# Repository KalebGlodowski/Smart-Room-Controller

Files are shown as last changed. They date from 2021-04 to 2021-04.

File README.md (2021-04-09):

# Kaleb's Smart Room Controller

## Overview
The purpose of this project is to increase automation within Blink (my cat)'s living environment.

1. Turn on the air freshener and hue lights when the cat is detected entering her litter box
1. Detect the temperature of the cat's room and light up LED's on the board accordingly.
		-flash hue lights when the temperature changes enough to change LED colors
1. 3D model a button knob for the encoder using this link: https://www.sparkfun.com/products/15141
		-click on the features tab in the link
1. Full user input to adjust hue lights
		-Change brightness via potentiometer
		-Change active light via encoder
		-Turn on active light with a single click
		-Change active light color with a long press
1. Keypad that takes in a passcode input
		-locks all user inputs when code is not entered
		-unlocks when correct passcode is entered
		-keypad can be re-locked via the '#' key

1. Display lock/unlock status on OLED

### The controller will have the ability to be manually controlled ontop of the automatic triggers.

## Details

This project uses the following components:

* Phillips hue lights
* Breadboard
* Wires
* Teensy 3.2 microcontroller
* Ultrasonic Sensor (the 2x giant silver circles) | Sends signal, encounters obstacle, then comes back and calculates distance

Can look into more parts: https://www.elegoo.com/products/elegoo-37-in-1-sensor-kit?_pos=1&_sid=ba0552267&_ss=r

## Summary

Automated hue lights, automated air-freshener through a Wemo outlet and fully adjustable hue lights through user input on the board.

You can find me on Hackster here: https://www.hackster.io/kalebglodowski .
And on LinkedIn here: https://www.linkedin.com/in/kalebglodowski/ .

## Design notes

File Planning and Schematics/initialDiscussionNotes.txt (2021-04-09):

Sensor to detect when cat enters litterbox and then send a signal to turn on airfreshener
	Airfreshener = Weemo ON + Wax melter outlet plug
	Sensor = ultrasonic sensor

Sensor to detect when cat goes to eat her food and turn on soft light
	hue lights ON, soft violet
	sensor = ultrasonic sensor

Detect how much water cat has left in her bowl and use the tubing to refill her water bowl /// not enough time/know-how

Pull weather data from online and then light a hue light depending on the temperature outside. Also light neoPixels depending on the rain status. //do not know how, nixed for time

Have the teensy turn on your computer when you press a button //do not know how and does not fit the theme

Allow Hue light to fully controllable manually via the buttons/encoder/potentiometer on the board

Require a password for to access the user manual controls

^ Above are the notable notes/ideas i discussed with my wife Zoe, my friend Austin, my mom, and Cecilia. Not all are included in the project.

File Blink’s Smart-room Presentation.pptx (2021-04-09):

## Blink’s Smart-room controller

created by kaleb glodowski

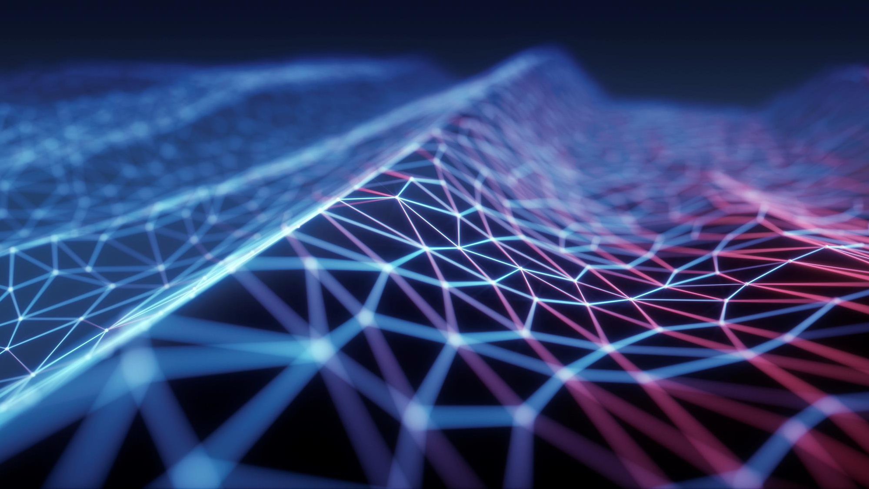
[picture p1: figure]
Digital Connections

## Overview

Planning
Code
Demo

## Planning | Fritzing and components

Components:
Teensy 3.2
Encoder
Potentiometer
Ultrasonic Sensor***
Ethernet port
BME sensor
OLED
NeoPixels & NeoPixel Ring
During the planning phase, I knew I wanted to incorporate most of the components we have learned to use thus far.
***Ultrasonic Sensor is a new component that we have not used yet that can detect and determine how far away an object is.

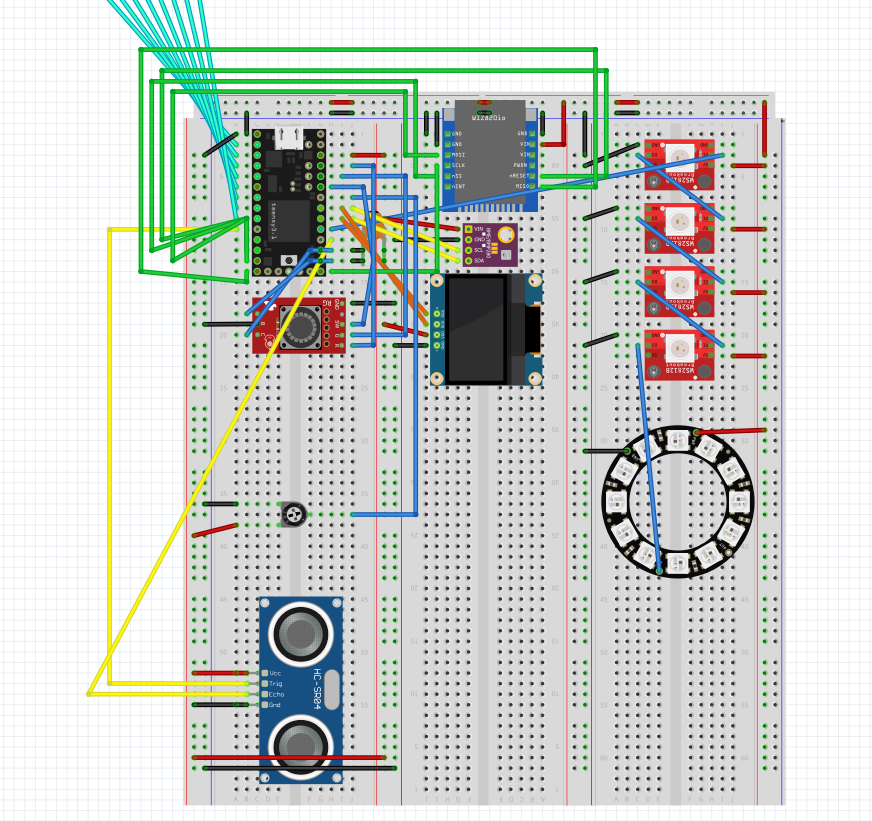
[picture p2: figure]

Note: The cyan wires go-to the keypad off-screen.

## Planning | Main features

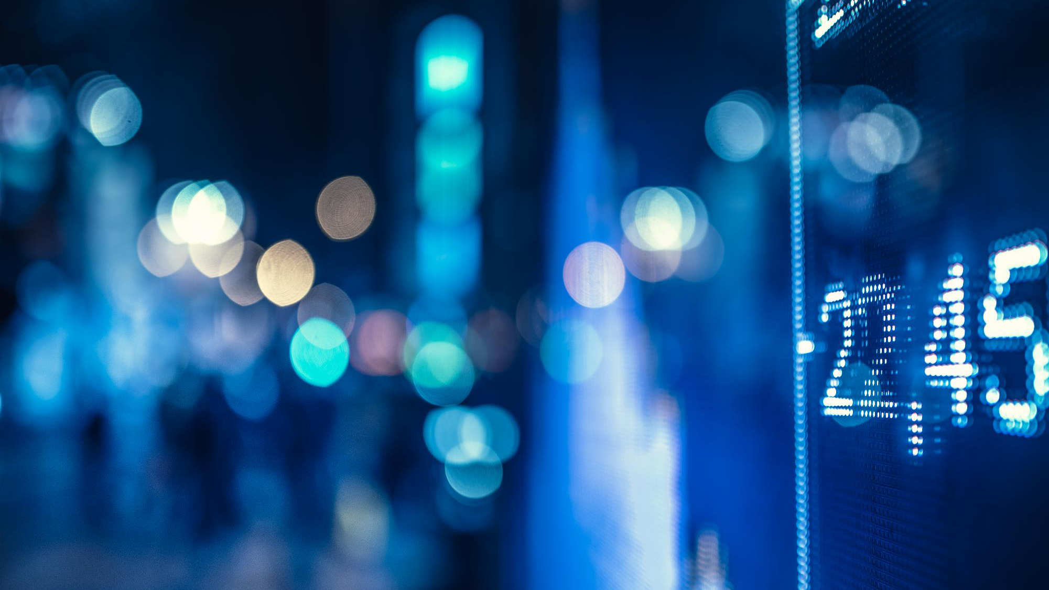
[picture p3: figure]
Digital Numbers

Temperature detection
Auto air-freshener
Full user-input light control

## Code

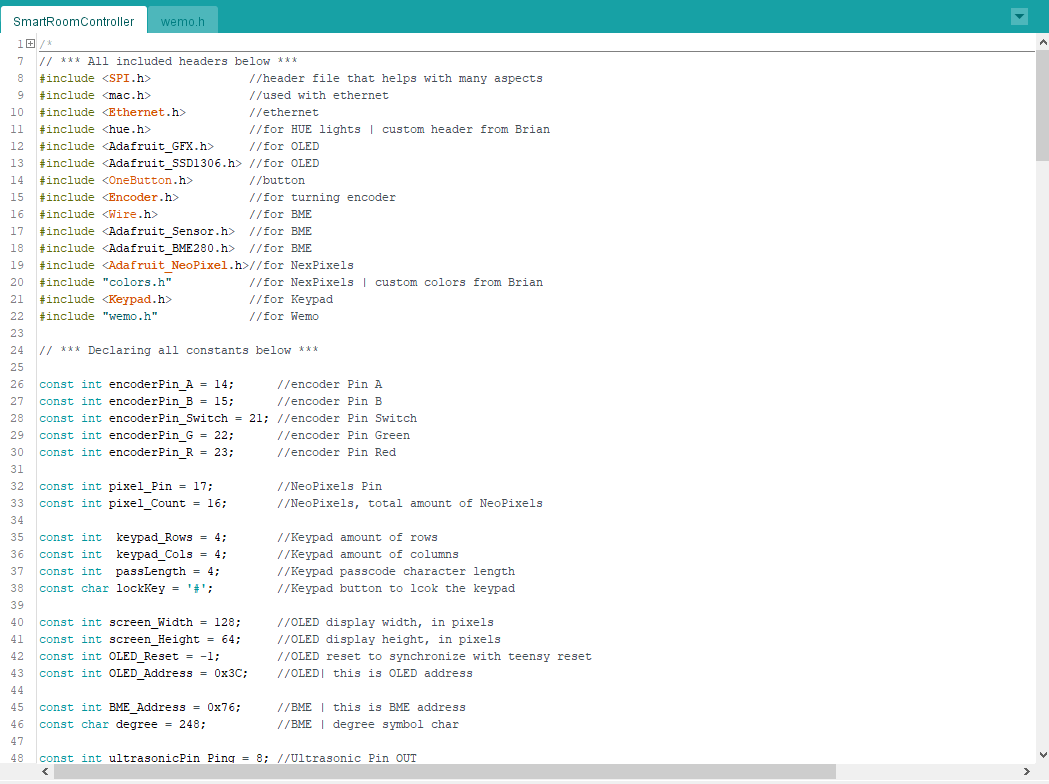
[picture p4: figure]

Main Focus | Organization
Knew that it would be a lot of code. Knowing what is going on in the hundreds of lines of code was essential.
Challenges | Weemo Outlet
>Interference from uSD reader
The ethernet port was checking to see if it was free to accept data but the uSD card was also plugged in and was returning a bunch of non-sense data through the same line (MISO). The code was then breaking when running code from the Weemo header.
To fix this, I had to turn off SPI devices. See code below:

## Demo | Outline

Automation

Manual

- BME
- Ultrasonic Sensor

- Keypad Lock
- Manual Air-Freshener
- Hue Control

## automation | BME & feedback

BME
NeoPixels
Hue Light
Reads the temperature in the room
Lights up red, yellow, or blue depending on the BME reading
Flashes the same color as the NeoPixels when there is a big enough temperature change to change the color of the NeoPixels. After the flash, the Hue lights will then revert back to their previous settings.

## automation | Ultrasonic sensor & Feedback

Ultrasonic Sensor
The ultrasonic sensor is going to detect if there is an object passing between the wall and itself. If there is, then it will automatically turn on the Weemo outlet and Hue lightbulbs.
Wemo
When the ultrasonic sensor detects something passing by, the Wemo outlet connected to air freshener will turn on for a set time. When the timer hits the specified time, the Wemo outlet will turn back off.
Hue Lights
The hue lights are acting as feedback and to light the room when the ultrasonic sensor detects an object passing it. These lights are on the same timer as the Wemo and will turn off automatically when the time is up.

  - As additional feedback, the encoder LED turns green while the Weemo and Hue lights are on, then turns back to red when they are off.

Encoder LED

## manual | keypad lock

Keypad Locked
Enter correct passcode
Keypad Unlocked
Enter the ‘#’ key

All user-input is not accessible while the keypad is locked.

Once the keypad is unlocked, the ‘#’ key can be entered to re-lock all manual inpuet.

OLED displays “LOCKED!”

A 4 digit passcode must be entered to unlock the keypad. When an incorrect digit is entered, you will be prompted to restart entering the code at position one(s=0).
If position 4(s=3) is entered correctly, the keypad will unlock.

All user-input is accessible once the keypad has been unlocked

OLED displays “UNLOCKED! ”

## manual | air freshener

Doubleclick button

The Wemo outlet will turn on/off.

The Hue lightbulbs will turn on/off.

A timer will auto turn off the lights if they are not manually turned off beforehand.

## manual | hue control

Click button

Long press button

Turn potentiometer

Turn encoder

turn on/off light

change color of light

change brightness of the light

change selected light

## Thank You

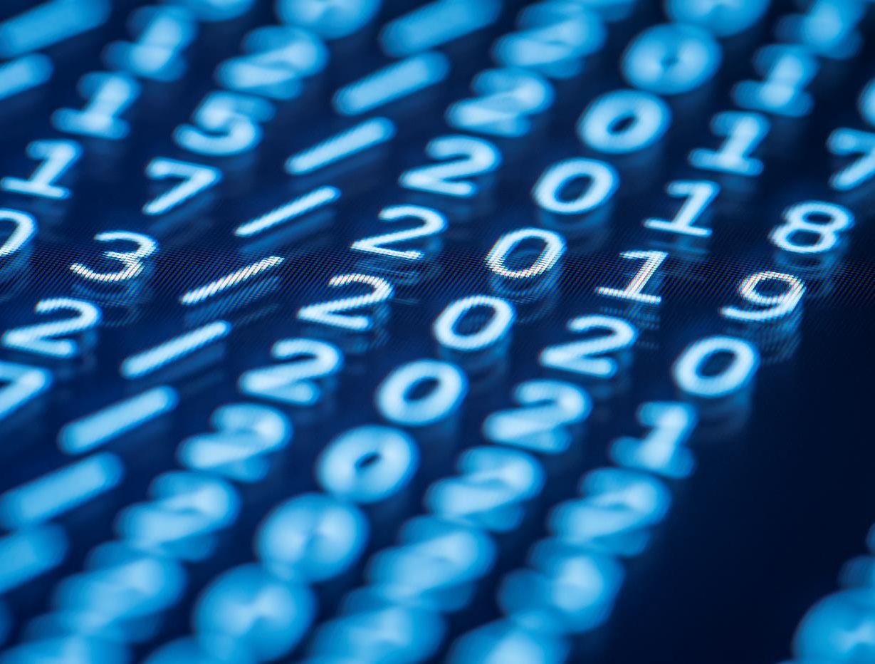
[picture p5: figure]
Digital Numbers

More from me:
https://github.com/KalebGlodowski
https://www.hackster.io/kalebglodowski
https://www.linkedin.com/in/kalebglodowski/

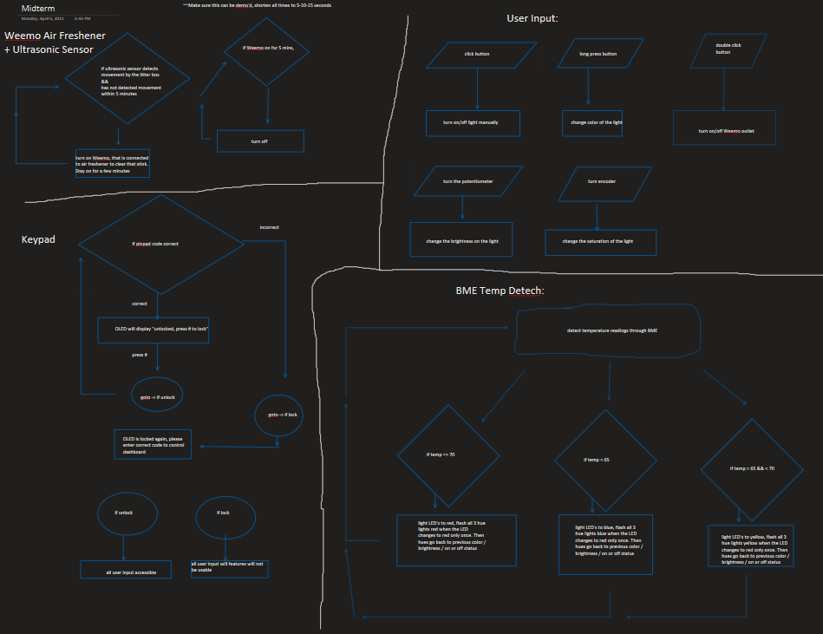
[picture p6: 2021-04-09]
Planning and Schematics/LogicDesign.png

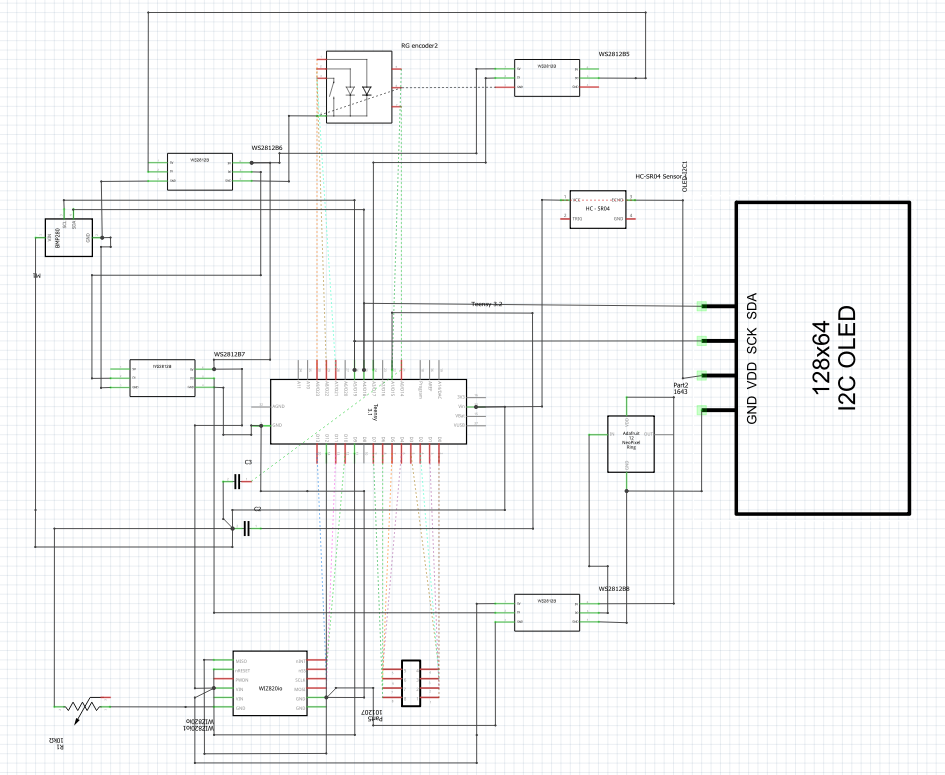
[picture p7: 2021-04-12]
Planning and Schematics/Smart Room Controller Schematic.png

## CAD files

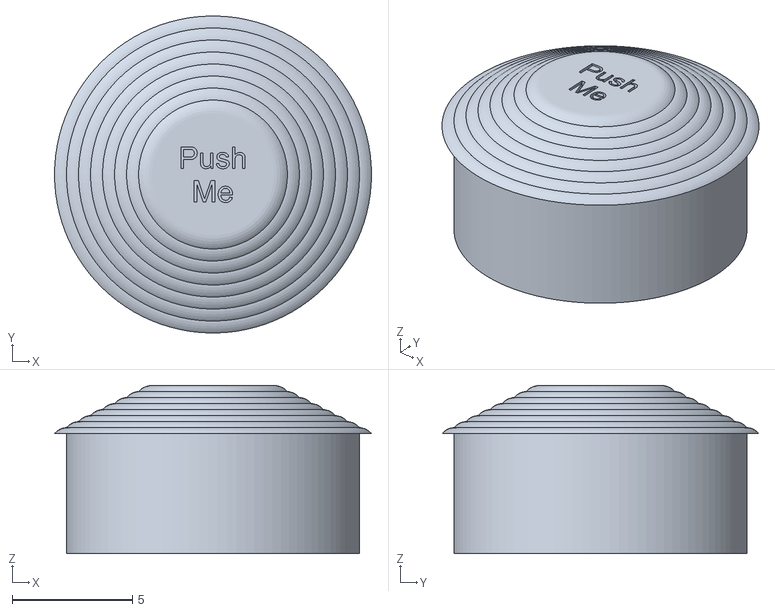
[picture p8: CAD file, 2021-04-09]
CAD/SmartController HalfButton v1.stl
13.2 x 13.2 x 7.00

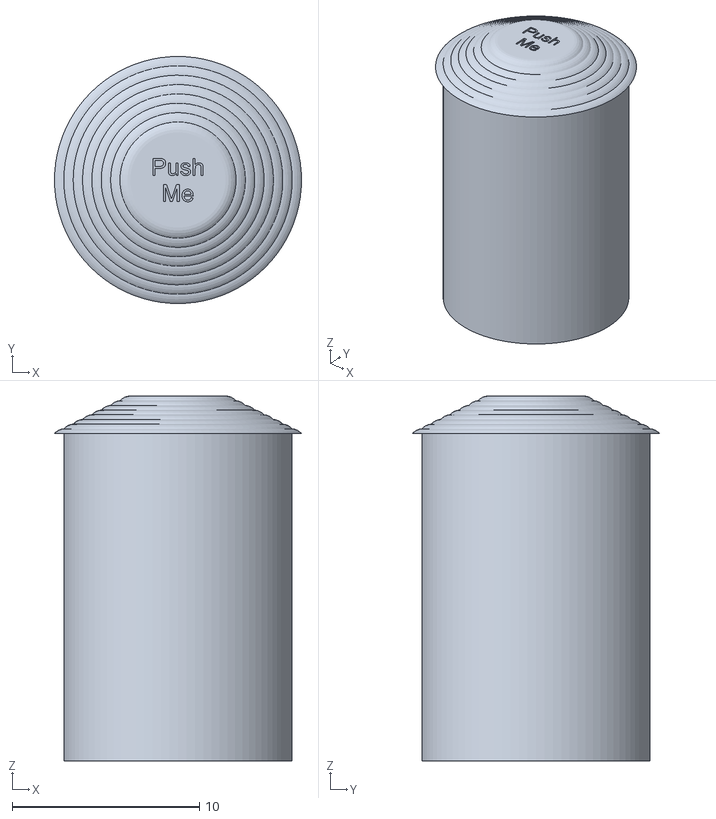
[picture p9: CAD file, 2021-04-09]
CAD/SmartController Button v1.stl
13.2 x 13.2 x 19.5

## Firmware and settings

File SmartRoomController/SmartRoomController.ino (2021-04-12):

/*
 *  Project:      Smart Room Controller Midterm
 *  Description:  See readme for overview.
 *  Authors:      Kaleb Glodowski
 *  Date:         06-APR-2021
 */
// *** All included headers below ***
#include <SPI.h>              //header file that helps with many aspects
#include <mac.h>              //used with ethernet
#include <Ethernet.h>         //ethernet
#include <hue.h>              //for HUE lights | custom header from Brian
#include <Adafruit_GFX.h>     //for OLED
#include <Adafruit_SSD1306.h> //for OLED
#include <OneButton.h>        //button
#include <Encoder.h>          //for turning encoder
#include <Wire.h>             //for BME
#include <Adafruit_Sensor.h>  //for BME
#include <Adafruit_BME280.h>  //for BME
#include <Adafruit_NeoPixel.h>//for NexPixels
#include "colors.h"           //for NexPixels | custom colors from Brian
#include <Keypad.h>           //for Keypad
#include "wemo.h"             //for Wemo

// *** Declaring all constants below ***

const int encoderPin_A = 14;      //encoder Pin A
const int encoderPin_B = 15;      //encoder Pin B
const int encoderPin_Switch = 21; //encoder Pin Switch 
const int encoderPin_G = 22;      //encoder Pin Green
const int encoderPin_R = 23;      //encoder Pin Red

const int pixel_Pin = 17;         //NeoPixels Pin
const int pixel_Count = 16;       //NeoPixels, total amount of NeoPixels

const int  keypad_Rows = 4;       //Keypad amount of rows
const int  keypad_Cols = 4;       //Keypad amount of columns
const int  passLength = 4;        //Keypad passcode character length
const char lockKey = '#';         //Keypad button to lcok the keypad 

const int screen_Width = 128;     //OLED display width, in pixels
const int screen_Height = 64;     //OLED display height, in pixels
const int OLED_Reset = -1;        //OLED reset to synchronize with teensy reset
const int OLED_Address = 0x3C;    //OLED| this is OLED address

const int BME_Address = 0x76;     //BME | this is BME address
const char degree = 248;          //BME | degree symbol char

const int ultrasonicPin_Ping = 8; //Ultrasonic Pin OUT
const int ultrasonicPin_Echo = 16;//Ultrasonic Pin IN

const int  selectWemo = 3;        //selects the 3rd Wemo within the Wemo header file. This is the only one I have.

const int potentiometerPin = 20;  //Potentiometer Pin IN

// *** Variables below ***

char hexaKeys [keypad_Rows] [keypad_Cols] = {     //Keypad | array for the buttons
  { '1', '2', '3', 'A'},
  { '4', '5', '6', 'B'},
  { '7', '8', '9', 'C'},
  { '*', '0', '#', 'D'}
};
char keyCode[passLength] = {'9', '4', '9', '6'};  //Keypad | passcode
byte rowPins[keypad_Rows] = {0, 1, 2, 3};         //Keypad | pins being used for the rows
byte colPins[keypad_Cols] = {4, 5, 6, 7};         //Keypad | pins being used for the columns
char keypadInput;                                 //Keypad | user input to the keypad
char s;                                           //Keypad | "s" is the spot the user is inputing a key for. ie: 0 is spot 1, 1 is spot 2, ect.
char keySequence[passLength];                     //Keypad | this is the code that the user has entered so far, will only go on to the nex character if correct
bool resetPosition;                               //Keypad | resetting the "s", reverting the user back to s=0, also known as position 1
bool keyState;                                    //Keypad | state of whether key is locked or unlocked
bool isLocked;                                    //Keypad | necessary to not have OLED spamming/flickering. This will be set true when locked, and turned false when unlocked.
  
bool BMEstatus;                   //BME | true/false variable set to BME's start status whether it is on or not.
int   tempC;                      //BME | celsius temperature
float tempF;                      //BME | fahrenheit temperature converted from celsius
int tempTime;                     //BME | timestamp when displaying temperature
int lastTemp;                     //BME | last temperature reading

int currentTime;                  //set to millis(), this is the time the code has been running

int lastSonicTime;                //Ultrasonic | a timestamp given after going through the ultrasonic IF statement
long duration;                    //Ultrasonic | duration
long inches;                      //Ultrasonic | inches from sensor

bool wemoOn;                      //Wemo | Is the Wemo on?
int wemoOnTime;                   //Wemo | Timestamp when the Weemo was turned on

int potRead;                      //Potentiometer readings

int hueBright;                    //Hue | light brightness level converted from potentiometer read
int lastHueBright;                //Hue | last brightness
int hueColor;                     //Hue | selected hue color
bool hueStatus;                   //Hue | is hue light on?
int saveBright;                   //Hue | saved brightness for hueflash
int saveColor;                    //Hue | saved color for hueflash
bool needHueRestore;              //Hue | restores to saved hue settings
int i;                            //Hue | used in the hue for loop to light all 3 lights
int previousColor;                //Hue | last hue color
int hueColorSelect[] = 
{HueOrange, HueYellow, HueViolet};//Hue | 3 colors to switch between utilizing the longPress
int c;                            //Hue | c is the color within the hueSelect, can be between 0 and 2
int hueLight;                     //Hue | the currently selected hue lightbulb

bool singleClickState;            //Button | a state that is changed with a single click
bool doubleClickState;            //Button | a state that is changed with a double click
bool longPressState;              //Button | a state that is changed with a long press

int lastPosition;                 //Encoder | remembering last position of encoder
int encPosition;                  //Encoder | current position of encoder

// *** Defining objects for the header files below ***

OneButton button1 (encoderPin_Switch, true, true);                                              //for Button
Encoder myEnc (encoderPin_A, encoderPin_B);                                                     //for Encoder
Adafruit_SSD1306 display(screen_Width, screen_Height, &Wire, OLED_Reset);                       //for OLED
Adafruit_NeoPixel pixel (pixel_Count, pixel_Pin, NEO_GRB + NEO_KHZ800);                         //for NeoPixels
Adafruit_BME280 bme;                                                                            //for BME
Wemo myWemo;                                                                                    //for Wemo
Keypad customKeypad = Keypad(makeKeymap(hexaKeys), rowPins, colPins, keypad_Rows, keypad_Cols); //for Keypad

void setup() {

  pinMode (ultrasonicPin_Ping, OUTPUT);                     //Ultrasonic Sensor | sending a signal out
  pinMode (ultrasonicPin_Echo, INPUT);                      //Ultrasonic Sensor | recieving a signal back
  pinMode (encoderPin_R,OUTPUT);                            //Encoder Red LED   | outputting a command from the Teensy to the board
  pinMode (encoderPin_G,OUTPUT);                            //Encoder Green LED | ''
  pinMode (potentiometerPin, INPUT);                        //Potentiometer     | recieving a reading of the position of the potentiometer
  Serial.begin(9600);

  //Below are necessary includes to ensure Wemo works  
  pinMode(10, OUTPUT);
  digitalWrite(10, HIGH);
  pinMode(4, OUTPUT);
  digitalWrite(4, HIGH);
  
  button1.attachClick(oneClick);                           //Button | single click
  button1.attachDoubleClick(doubleClick);                  //Button | double click
  button1.attachLongPressStart(longPress);                 //Button | long click
  button1.setClickTicks(250);                              //Button | knows the difference between a single click and a double click
  button1.setPressTicks(1000);                             //Button | how long to be considered a long press  

  delay(100);
  Serial.printf("Starting OLED and BME ...\n");  
  if (!display.begin(SSD1306_SWITCHCAPVCC, OLED_Address)) { //REQUIRED LINE FOR OLED TO BEGIN WITH HEX ADDRESS OF OLED, CHECKS IF WORKING
    Serial.printf("Error beginning display.\n");
    return;
  }
  else {
    Serial.printf("Display has started successfully.\n");
  }
  _clearDisplay();
  display.setTextSize(2);                                   //OLED | Draw "2"X-scale text
  display.setTextColor(SSD1306_WHITE);                      //OLED | setting text color  
  
  BMEstatus = bme.begin(BME_Address);                       //REQUIRED LINE TO BEGIN BME WITH HEX ADDRESS OF BME, CHECK IF WORKING BELOW
  if (BMEstatus == false) {
    Serial.printf("BME280 not detected. Check BME address and wiring.\n");
  }
  else {
    Serial.printf("BME280 has been detected.\n");    
  }

  pixel.begin();                                            //REQUIRED LINE TO BEGIN PIXELS
  pixel.show();

  Serial.printf("Detecting ethernet link ...\n");
  Ethernet.begin(mac);                                      //REQUIRED LINE TO BEGIN ETHERNET LINK
  printIP();
  Serial.printf("LinkStatus: %i  \n",Ethernet.linkStatus());
  
  myWemo.switchOFF(selectWemo);                             //Ensuring myWemo is off
  delay(1000);
  wemoOn = false;                                           //Ensuring wemoOn is false
  hueStatus = false;                                        //Ensuring hue lights are turned off
  hueLight = 1;                                             //hueLight will start with first one active
  hueBright = 80;
  for (i=1; i <= 3; i++) {
    setHue(i, hueStatus, hueColor, hueBright, 255);
  }    
  Serial.printf("Finished setup.\n");
}

void loop() {

  button1.tick();                                               //required for button to work
  currentTime = millis();  
  if (isCatThere() == true && wemoOn == false) {                //turns on Wemo if cat is there
    airFreshenerOn();
  }
  if ((currentTime - wemoOnTime) > 10000 && wemoOn == true) {   //turns off Wemo after 10 seconds of being on
    airFreshenerOff();  
  }
  roomTempDetect();
  isKeyUnlocked();
  encoderTurn();
  pMeterToBright();  
}

//******* ALL USER INPUT FUNCTIONS HAVE AN "IF UNLOCKED" PRIOR TO ANY CODE ||| KEYPAD MUST BE USED TO UNLOCK FIRST*******

void oneClick() {                                         //manually turn on/off the hue lights
  if (isKeyUnlocked() == true) {
    singleClickState = !singleClickState;
    Serial.printf("Button has been clicked a single time.\n");
    if (singleClickState == true) {
      Serial.printf("Single click on state.\n");    
      hueStatus = true;
      setHue(hueLight, hueStatus, hueColorSelect[c], hueBright, 255);
    }
    if (singleClickState == false) {
      Serial.printf("Single click off state.\n");    
      hueStatus = false;
      setHue(hueLight, hueStatus, hueColorSelect[c], hueBright, 255);    
    }    
  }
}

void doubleClick() {                                      //manually turn on/off the airfreshener + violet hue lights
  if (isKeyUnlocked() == true) {  
    Serial.printf("Button has been double clicked.\n");  
    doubleClickState = !doubleClickState;
    if (doubleClickState == true) {
      Serial.printf("Double click on state.\n");
      airFreshenerOn();
    }
    if (doubleClickState == false) {
      Serial.printf("Double click off state.\n");
      airFreshenerOff();
    }
  }
}

void longPress() {                                        //manually change the color of the hue lights
  if (isKeyUnlocked() == true) {
    //make something sweet happen on the OLED screen! But make sure it reverts back to whatever it was displaying last time
    Serial.printf("Button has been long pressed.\n");    
    longPressState = !longPressState;
    if (longPressState == true) {
      Serial.printf("Cycling to the next color. Must turn off/on the hue to apply this change.");
      c = c + 1;   //c represents the spot in the array for hueColorSelect
      if (c > 2) { //c can only be 0, 1, or 2
        c = 0;
      }      
    }
  }
}

void encoderTurn() {                                      //manually change the saturation levels of the hue
  if (isKeyUnlocked() == true) {
    encPosition = myEnc.read();
    if (lastPosition != encPosition) {
      Serial.printf("The current encoder positin is: %i.\n", encPosition);
      if (encPosition < 0) {
        encPosition = 0;
        Serial.printf("encPosition being set to 0. Do not try to turn below 0.");
      }
      if (encPosition > 99) {
        encPosition = 99;
        Serial.printf("encPosition being set to 99. Do not try to go beyond 99.");
      }
      hueLight = map(encPosition,0,99,1,3);
      Serial.printf("The current hue lightbulb selected is: %i.\n", hueLight);
      lastPosition = encPosition;
    }  
  }
}

bool isKeyUnlocked () {                                   //keypad lock and unlock function
  keypadInput = customKeypad.getKey();  //establishes user input  
  if (resetPosition == true) {
    s = 0;
  }
  if (keypadInput == lockKey && keyState == true) {                             //this gives the keypad a functionality of being re-locked after being locked
    keyState = false;
    keySequence[3] = NULL; //resetting the keySequence
    keySequence[2] = NULL;
    keySequence[1] = NULL;
    keySequence[0] = NULL;
    resetPosition = true; //resetting position back to 1
    Serial.printf("Key # pressed. Locking keypad.\n");
    Serial.printf("To access user input features, please re-enter the passcode.\n");
    return false;
  }
  if (keypadInput && keyState == false) {                                       //this is the main keycode if function that compares user input char to keyCode
    Serial.printf("Key %c has been pressed.\n", keypadInput);
    Serial.printf("Currently entering character in the %i position.\n", (s+1)); //s+1 because first place would show a 0 and we want the user to see a 1
    if (keyCode[s] == keypadInput) {
      Serial.printf("Position %i key unlocked.\n", (s+1));
      keySequence[s] = keypadInput;
      resetPosition = false;
    }
    else {
      resetPosition = true;
      Serial.printf("Password incorrect for position %i. Resetting.\n", (s+1));
    }
    s = s+1;
  }
  if (keySequence[3] == keyCode[3]) {
    if (keyState == false) {
      Serial.printf("Password has been entered corrrect. User input is unlocked.\n");
      _clearDisplay();
      display.setTextSize(1); // Draw 1X-scale text      
      display.printf("All user input is currently:\n");
      display.setTextSize(2); // Draw 2X-scale text, 3X scale does not fit well with such a long word
      display.printf("UNLOCKED!\n");
      display.setTextSize(1);
      display.printf("Press '#' to lock.");
      executeDisplay(); 
      keyState = true; //this is put in place to keep the above line from spamming
      isLocked = false;
    }
    return true;  //returns a true for the isKeyLocked function
  }
  else {
    if (isLocked != true) {
     _clearDisplay();
    display.setTextSize(1); // Draw 1X-scale text      
    display.printf("All user input is currently:\n");
    display.setTextSize(3); // Draw 3X-scale text
    display.printf("LOCKED!");
    executeDisplay();
    isLocked = true;     
    }
    
    return false; //returns a false for the isKeyLocked function
  }
}

void roomTempDetect() {                                   //detects the temperature in the room and lights the NeoPixels accordingly
  
  tempC = bme.readTemperature(); //reading temp in celsius
  tempF = ((tempC * 9/5) + 32);  //converting to fahrenheit
  if ((currentTime - tempTime) > 10000 && tempF != lastTemp) {
    Serial.printf("Room temperature is currently %f%c fahrenheit.\n", tempF, degree);   //Serial.print does not display degree character properly | this is normal.
    pixel.clear();
    pixel.show();
    if (tempF >= 70) {
      Serial.printf("Temperature is great than or equal to 70 degrees. Lighting pixels to red.\n");
      pixel.fill(red, 0, pixel_Count);
      pixel.setBrightness(30);
      pixel.show();
      hueFlash(red);
    }
    if (tempF < 65) {
      Serial.printf("Temperature is less than 65 degrees. Lighting pixels to blue.\n");
      pixel.fill(blue, 0, pixel_Count);
      pixel.setBrightness(30);
      pixel.show();
      hueFlash(blue);      
    }
    if (tempF >= 65 && tempF < 70) {
      Serial.printf("Temperature is greater than or equal to 65 and less than 70. Lighting pixels to yellow.\n");      
      pixel.fill(maize, 0, pixel_Count);
      pixel.setBrightness(30);
      pixel.show();
      hueFlash(yellow);
    }
    lastTemp = tempF;
    tempTime = millis();    
  }
}

void hueFlash(int tempColor) {                            //Flashes the hue lights when the temperature changes
  saveBright = hueBright;
  saveColor = hueColor;
  if (tempColor == red && tempColor != previousColor) {   //put in tempColor != previousColor because we do not want to flash unless changing temperature colors
    hueBright = 255;
    hueColor = HueRed;
    for (i=1; i <= 3; i++) {
      setHue(i, true, hueColor, hueBright, 255);
    }  
    previousColor = tempColor;
    Serial.printf("Flashing red.\n");
    needHueRestore = true;               
  }
  if (tempColor == yellow && tempColor != previousColor) {
    hueBright = 255;
    hueColor = HueYellow;
    for (i=1; i <= 3; i++) {
      setHue(i, true, hueColor, hueBright, 255);
    }
    previousColor = tempColor;
    Serial.printf("Flashing yellow.\n");   
    needHueRestore = true;                       
  }    
  if (tempColor == blue && tempColor != previousColor) {
    hueBright = 255;
    hueColor = HueBlue;
    for (i=1; i <= 3; i++) {
      setHue(i, true, hueColor, hueBright, 255);
    } 
    previousColor = tempColor;   
    Serial.printf("Flashing blue.\n");
    needHueRestore = true;                
  }
  if (needHueRestore == true) {
    hueColor = saveColor;
    hueBright= saveBright;
    delay(3000);
    for (i=1; i <= 3; i++) {  
    setHue(i, hueStatus, hueColor, hueBright, 255);   //reverting hue lights back to previous hue settings    
    }
    Serial.printf("Hue lights have been restored to settings prior to flash.\n");
  }
}

int pMeterToBright() {                                    //converts potentiometer readings to brightness for the Hue Light
  if (isKeyUnlocked() == true) {
    potRead = analogRead(potentiometerPin);
    hueBright = map(potRead,0,1024,0,255);
    if (hueBright != lastHueBright) {                               //ensures only printing brightness when it changes
      Serial.printf("Brightness changed to: %i.\n", hueBright);
      lastHueBright = hueBright; 
    }
    return hueBright;
  }
}

void executeDisplay() {                                   //this function is to display 
  display.setCursor(0,0);
  display.display(); //displaying  
}

void _clearDisplay() {                                    //this function clears display
  display.clearDisplay();
  display.display();
}

void airFreshenerOn() {                                   //turns on the Weemo outlet and hue lights
  myWemo.switchON(selectWemo);    //Commenting out all Wemo functionality due to an error in the header file on line 23 completely stopping all code.
  delay(100);
  wemoOnTime = millis();
  wemoOn = true; 
  digitalWrite(encoderPin_R, LOW);              //Encoder | turning red LED off
  digitalWrite(encoderPin_G, HIGH);             //Encoder | turning green LED on
  Serial.printf("Wemo has turned on.\n");
  hueStatus = true;
  for (i=1; i <= 3; i++) {
    setHue(i, hueStatus, hueColorSelect[2], hueBright, 255); //hueColorSelect[2] is the purple
  }   
  Serial.printf("Turning on the lights for the cat.");
  
}

void airFreshenerOff() {                                  //turns off Weemo outlet and hue lights
  myWemo.switchOFF(selectWemo);  //Commenting out all Wemo functionality due to an error in the header file on line 23 completely stopping all code.
  delay(100);
  wemoOn = false;
  digitalWrite(encoderPin_R, HIGH);              //Encoder | turning red LED on
  digitalWrite(encoderPin_G, LOW);               //Encoder | turning green LED off  
  Serial.printf("Wemo has turned off.\n");
  hueStatus = false;
  for (i=1; i <= 3; i++) {
    setHue(i, hueStatus, hueColor, hueBright, 255);
  }  
  Serial.printf("Turning the lights off.\n");    
}

void printIP() {                                          //ensures ethernet is working properly and prints ip
  Serial.printf("My IP address: ");
  for (byte thisByte = 0; thisByte < 3; thisByte++) {
    Serial.printf("%i.",Ethernet.localIP()[thisByte]);
  }
  Serial.printf("%i\n",Ethernet.localIP()[3]);
}
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

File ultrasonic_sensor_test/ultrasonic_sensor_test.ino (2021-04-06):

const int pingPin = 8; // Trigger Pin of Ultrasonic Sensor
const int echoPin = 16; // Echo Pin of Ultrasonic Sensor

void setup() {
   Serial.begin(9600); // Starting Serial Terminal
}

void loop() {
   long duration, inches, cm;
   pinMode(pingPin, OUTPUT);
   digitalWrite(pingPin, LOW);
   delayMicroseconds(2);
   digitalWrite(pingPin, HIGH);
   delayMicroseconds(10);
   digitalWrite(pingPin, LOW);
   pinMode(echoPin, INPUT);
   duration = pulseIn(echoPin, HIGH);
   inches = microsecondsToInches(duration);
   cm = microsecondsToCentimeters(duration);
   Serial.print(inches);
   Serial.print("in, ");
   Serial.print(cm);
   Serial.print("cm");
   Serial.println();
   delay(100);
}

long microsecondsToInches(long microseconds) {
   return microseconds / 74 / 2;
}

long microsecondsToCentimeters(long microseconds) {
   return microseconds / 29 / 2;
}

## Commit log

2021-04-06 first start to midterm
    [Smart Room Controller midterm fritz.fzz]
2021-04-06 before inserting ultrasonic
2021-04-07 completed all button inputs, beginning keypad
2021-04-08 completed all button functionality. Moving on to longPress for color control and then encoder for saturation control
2021-04-08 implemented OLED, fixed some small things
    [SmartRoomController.ino]
2021-04-09 small changes to code, added in powerpoint presentation, updated readme and cleaned up fritzing
    [Smart Room Controller midterm fritz.fzz]
2021-04-09 Added CAD. Re-organized folders. Small updates.
    [Smart Room Controller midterm fritz.fzz, SmartController Button v1.stl, SmartController HalfButton v1.stl]
2021-04-12 Updated powerpoint with CAD pictures. Updated code pMeterToBright to get brightness working properly.
2021-04-12 Added in more cad files
2021-04-12 Added new cad image to presentation
2021-04-12 updates schematics, cleaned up and made it look a lot more readable.
    [Smart Room Controller midterm fritz.fzz]
